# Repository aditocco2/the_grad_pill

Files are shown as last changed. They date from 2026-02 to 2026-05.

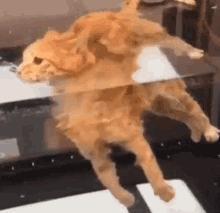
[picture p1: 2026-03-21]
python/media_test/iuh.gif

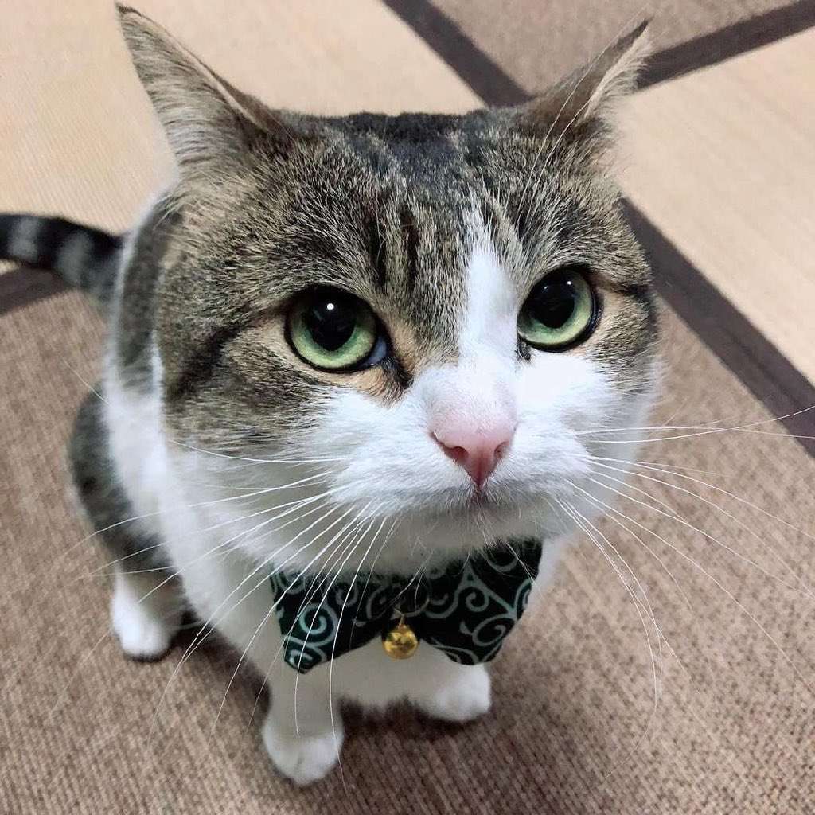
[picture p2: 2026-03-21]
python/media_slideshow/825763.jpg

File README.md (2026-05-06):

# Overblinking: The LED Matrix Graduation Cap

A DIY graduation cap project that shows a slideshow of pictures, GIFs, videos, and scrolling text messages on a 64x64 LED matrix.

Includes a high-performance LED matrix driver, a custom 3D printed mounting system, and a custom PCB.

thumb
staticmodetopdown
modesw

## Features
- Easy loading of data onto the SD card - no manual downscaling or image dumping needed
- SD card is exposed underneath the cap with a custom PCB, allowing easy replacement of cards
- Mode switch allows you to automatically switch to a less distracting "static mode" during speeches
- Whole system is powered through one battery pack
- Optional rain resistance using an acrylic sheet and 3D printed waterproofing shield
- Automatically initializes/recovers SD cards and survives card swaps
- Only required electronics skill for assembly is through-hole soldering

## Build Your Own
For instructions on how to make your own LED matrix graduation cap, read the full guide [here](https://overblinking.substack.com/guide)!

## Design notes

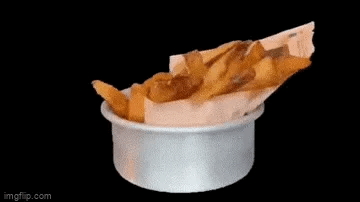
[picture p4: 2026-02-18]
python/media_slideshow/fries2.gif

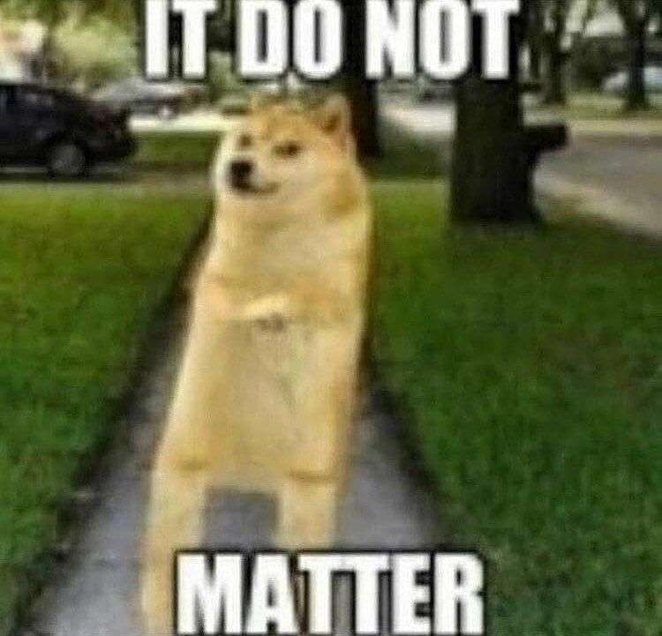
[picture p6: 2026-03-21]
python/media_slideshow/it do not matter.jpg

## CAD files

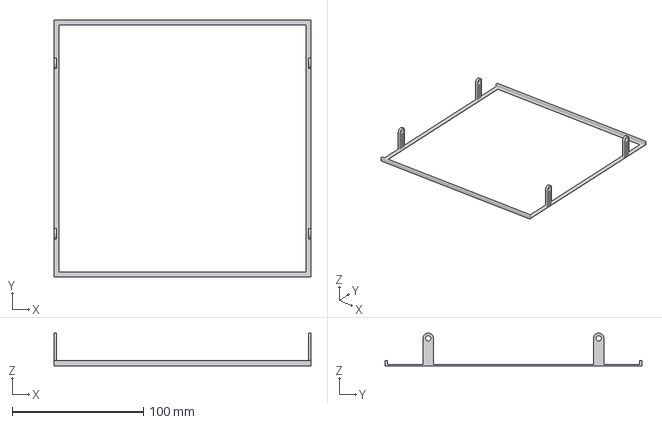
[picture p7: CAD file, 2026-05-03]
models/waterproofing_shield_2.3mf
196.0 x 196.0 x 25.0 mm

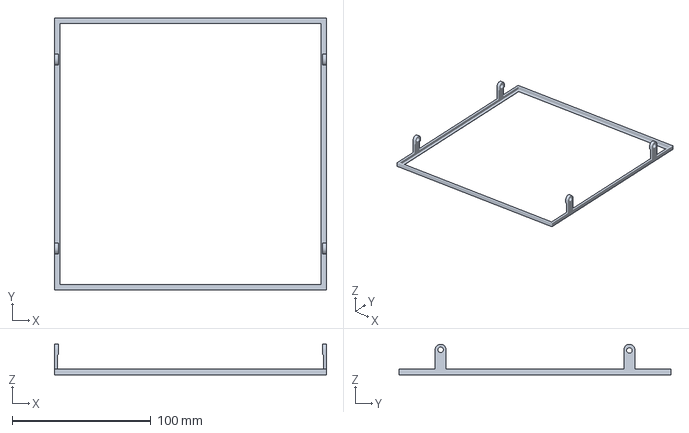
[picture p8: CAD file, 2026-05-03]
models/waterproofing_shield_1.3mf
196.0 x 196.0 x 22.0 mm

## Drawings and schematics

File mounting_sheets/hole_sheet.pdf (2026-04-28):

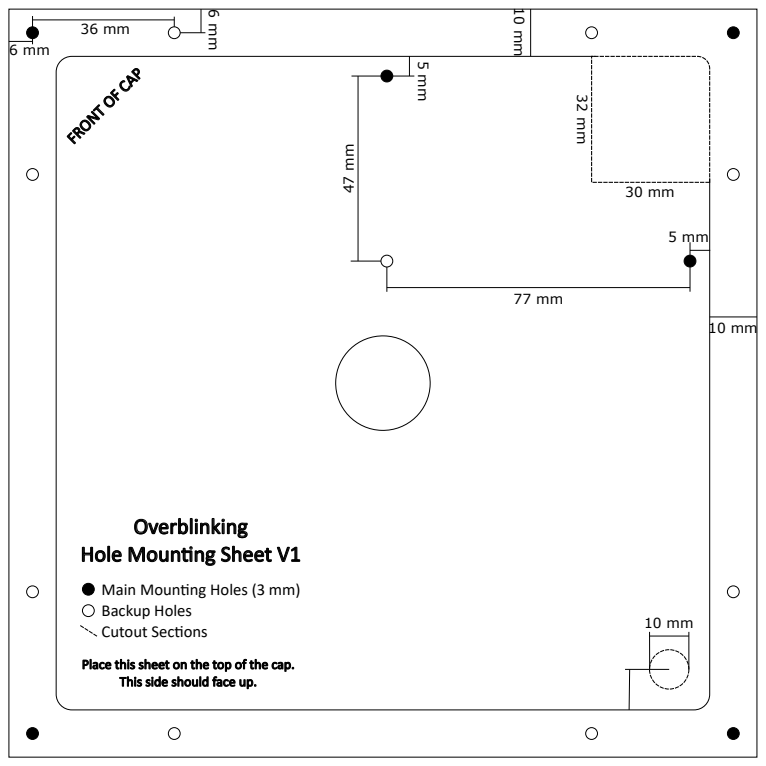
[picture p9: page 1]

FRONT OF CAP

Overblinking
Hole Mounng Sheet V1

Main Mounng Holes (3 mm)
Backup Holes
Cutout Secons

Place this sheet on the top of the cap.
This side should face up.

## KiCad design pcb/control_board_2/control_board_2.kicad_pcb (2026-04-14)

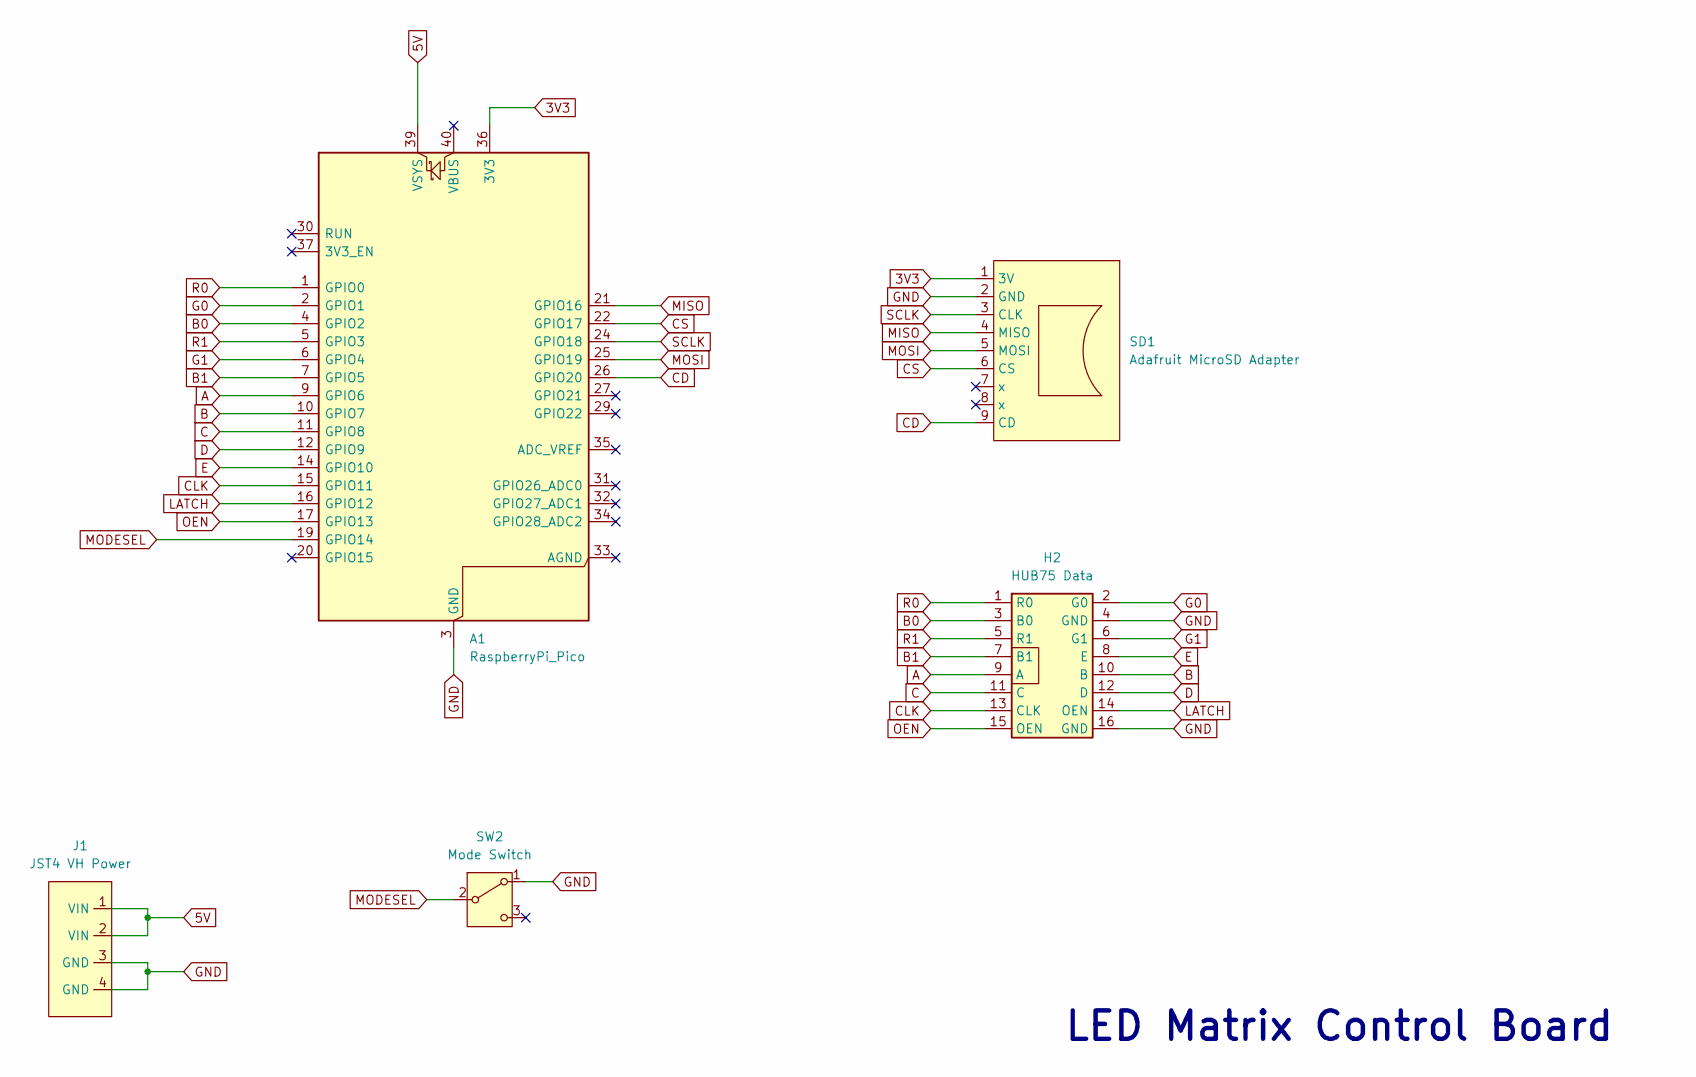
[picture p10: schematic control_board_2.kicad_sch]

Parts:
A1: RaspberryPi_Pico; RaspberryPi_Pico_Common_Unspecified
H2: HUB75 Data; IDC-Header_2x08_P2.54mm_Vertical
J1: JST4 VH Power; JST_VH_B4PS-VH_1x04_P3.96mm_Horizontal
SD1: Adafruit MicroSD Adapter; usd_breakout_adafruit
SW2: Mode Switch; SW_Slide-03_Wuerth-WS-SLTV_10x2.5x6.4_P2.54mm

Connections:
3V3: A1.36 (3V3), SD1.1 (3V)
5V: A1.39 (VSYS), J1.1 (VIN), J1.2 (VIN)
A: A1.9 (GPIO6), H2.9 (A)
B: A1.10 (GPIO7), H2.10 (B)
B0: A1.4 (GPIO2), H2.3 (B0)
B1: A1.7 (GPIO5), H2.7 (B1)
C: A1.11 (GPIO8), H2.11 (C)
CD: A1.26 (GPIO20), SD1.9 (CD)
CLK: A1.15 (GPIO11), H2.13 (CLK)
CS: A1.22 (GPIO17), SD1.6 (CS)
D: A1.12 (GPIO9), H2.12 (D)
E: A1.14 (GPIO10), H2.8 (E)
G0: A1.2 (GPIO1), H2.2 (G0)
G1: A1.6 (GPIO4), H2.6 (G1)
GND: A1.3 (GND), A1.8 (GND), A1.13 (GND), A1.18 (GND), A1.23 (GND), A1.28 (GND), A1.38 (GND), H2.4 (GND), H2.16 (GND), J1.3 (GND), J1.4 (GND), SD1.2 (GND), SW2.1 (A)
LATCH: A1.16 (GPIO12), H2.14 (OEN)
MISO: A1.21 (GPIO16), SD1.4 (MISO)
MODESEL: A1.19 (GPIO14), SW2.2 (B)
MOSI: A1.25 (GPIO19), SD1.5 (MOSI)
OEN: A1.17 (GPIO13), H2.15 (OEN)
R0: A1.1 (GPIO0), H2.1 (R0)
R1: A1.5 (GPIO3), H2.5 (R1)
SCLK: A1.24 (GPIO18), SD1.3 (CLK)

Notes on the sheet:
LED Matrix Control Board

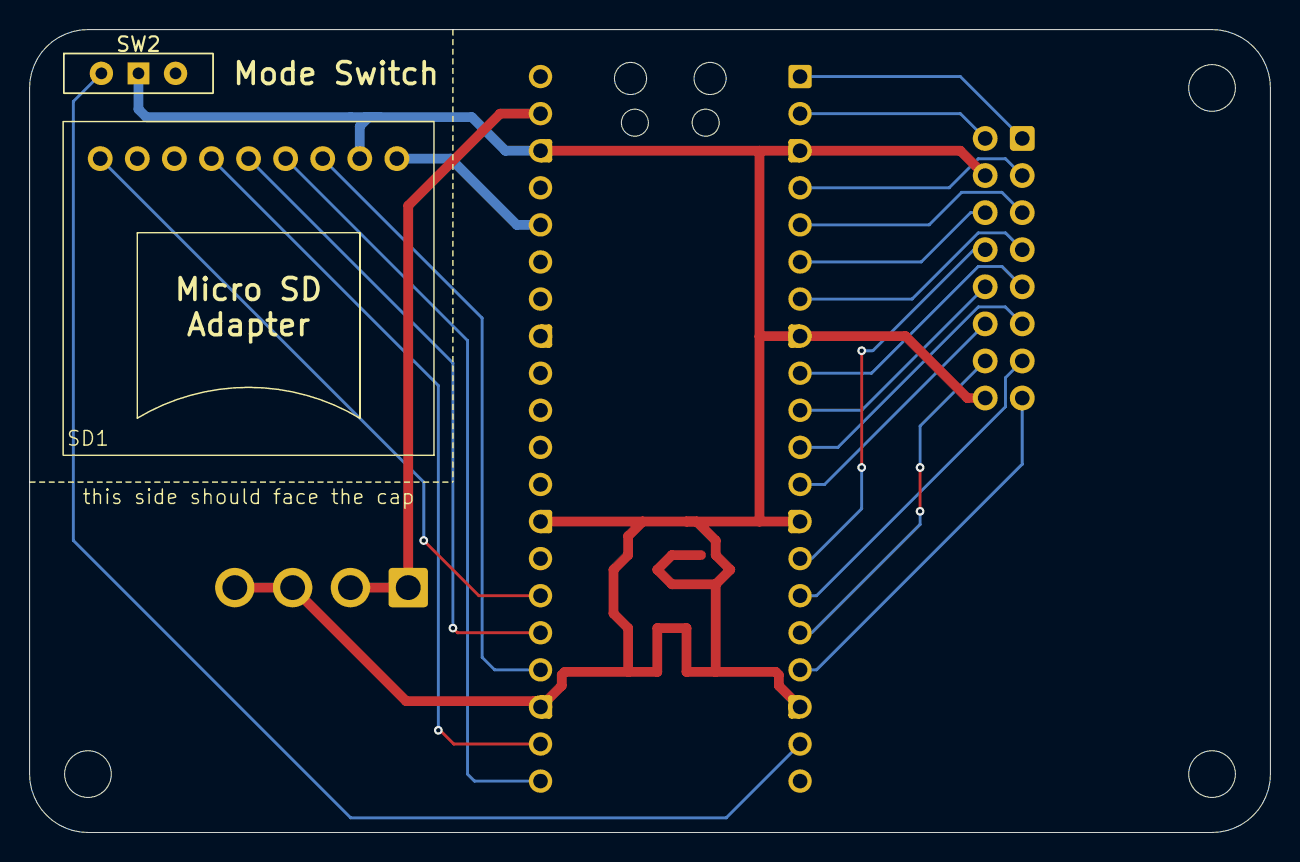
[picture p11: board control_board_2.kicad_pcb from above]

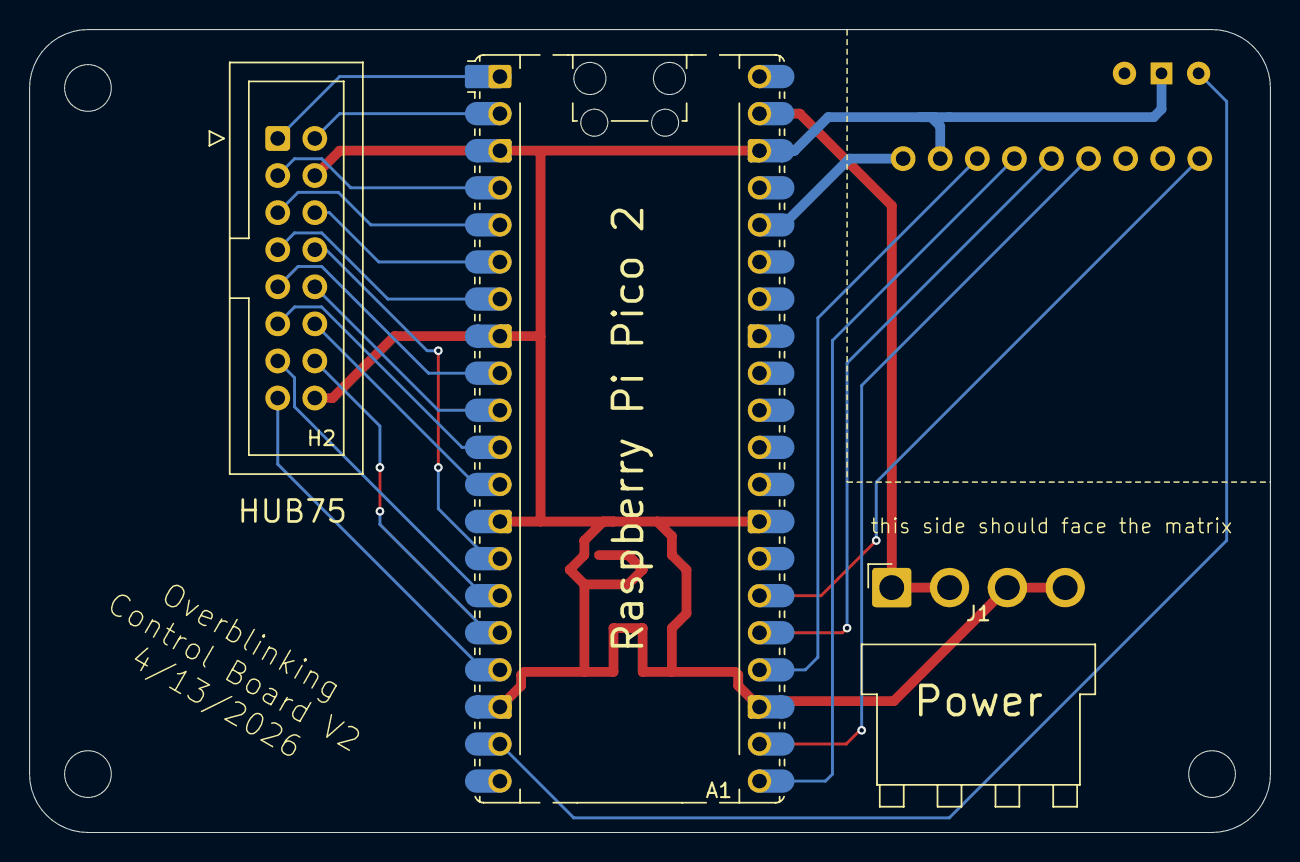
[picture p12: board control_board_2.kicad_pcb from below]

Board: 2 copper layers, 85.0 x 55.0 mm, 5 parts (3 on the bottom side), 23 nets.

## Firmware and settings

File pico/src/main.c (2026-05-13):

// just one more state machine bro, that's all i need

#include <stdio.h>
#include <stdint.h>
#include <string.h>
#include "pico/stdlib.h"
#include "pico/rand.h"
#include "pico/time.h"

#include "sd_card.h"
#include "hub75.h"
#include "hub75_text.h"
#include "rgb565_colors.h"

#define MAX_MEDIA 300
#define TEXT_SCROLLING_PIXELS_PER_SECOND 40

#define TEXT_INST_SEPARATION 16

#define SECTORS_PER_FRAME (WIDTH * HEIGHT * 2 / BLOCK_SIZE)

#define NUM_MEDIA_INDEX 0
#define SWITCH_INTERVAL_INDEX 4
#define USE_STATIC_MODE_INDEX 6
#define RANDOMIZE_INDEX 7

#define TABLE_ROW_WIDTH 16

#define MEDIA_SECTOR_ADDR_INDEX 0
#define N_FRAMES_INDEX 4
#define FRAME_TIME_INDEX 8
#define MEDIA_TYPE_INDEX 15

#define MODESEL 14
#define STATIC_SWITCH_VALUE 0
#define SLIDESHOW_SWITCH_VALUE 1

typedef enum {TEXT, IMAGE, VIDEO} media_type_t;
typedef enum {STATIC, SLIDESHOW} mode_t;

typedef struct{
    uint16_t switch_interval_s;
    _Bool use_static_mode;
    _Bool randomize;

    mode_t current_mode;

    media_type_t current_media_type;
    uint32_t media_address;
    uint16_t frame_duration_ms;
    uint32_t current_media_index;
    uint32_t current_frame_num;
    uint32_t num_frames_in_video;
    uint32_t pool_size;
} player_data_t;

void main_fsm();

void slideshow_media_index_fsm(player_data_t *ts, _Bool reset);
_Bool player_get_metadata(player_data_t *ts, uint8_t *temp_buffer);
_Bool player_load_media(player_data_t *ts, uint8_t *temp_buffer);
_Bool player_get_frame(player_data_t *ts, uint8_t *frame_buffer);
_Bool text_scrolling_fsm(player_data_t *ts, char *str, _Bool reset);
uint16_t color_cycle_rgb565_fsm(_Bool reset);
_Bool mode_switched(player_data_t *ts);
void fill_array_sequentially(uint32_t *arr, uint32_t len);
void shuffle_array(uint32_t *arr, uint32_t len);
void clear_screen();

// Basic timer callbacks that just set flags
struct repeating_timer media_switch_timer, frame_switch_timer;
_Bool media_switch_flag, frame_switch_flag;
_Bool media_switch_cb(__unused repeating_timer_t *rt) {media_switch_flag = true;}
_Bool frame_switch_cb(__unused repeating_timer_t *rt) {frame_switch_flag = true;}

int main(){
    stdio_init_all();

    hub75_configure();
    hub75_set_brightness(20);

    gpio_init(MODESEL);
    gpio_pull_up(MODESEL);
    gpio_set_dir(MODESEL, GPIO_IN);

    while(67){
        main_fsm();
    }
}

void main_fsm(){
    static enum {INIT, GET_METADATA, INVALID_CARD, SWITCH_MODE, 
                 LOAD_MEDIA, INITIALIZE_MEDIA, PLAY_MEDIA} state;

    static player_data_t ts;
    
    static _Bool sd_succ = true;

    uint8_t temp_buffer[BLOCK_SIZE];
    uint8_t *frame_buffer = (uint8_t *)hub75_get_back_buffer();

    if(!sd_succ){
        clear_screen();
        hub75_write_large_text("Insert", 32, 32, ALIGN_CENTER, ALIGN_BOTTOM, RGB565_Red);
        hub75_write_large_text("SD Card", 32, 32, ALIGN_CENTER, ALIGN_TOP, RGB565_Red);
        hub75_update();
        state = INIT;
    }

    switch(state){
        case INIT:
            sd_succ = sd_card_init();
            state = GET_METADATA;
            break;

        case GET_METADATA:
            sd_succ = player_get_metadata(&ts, temp_buffer);
            
            if((*(uint32_t *)&temp_buffer[12]) == 0xe3bedded){
                slideshow_media_index_fsm(&ts, true);
                state = SWITCH_MODE;
            }
            else{
                state = INVALID_CARD;
            }
            break;

        case INVALID_CARD:
            clear_screen();
            hub75_write_large_text("Invalid", 32, 32, ALIGN_CENTER, ALIGN_BOTTOM, RGB565_Red);
            hub75_write_large_text("SD Card", 32, 32, ALIGN_CENTER, ALIGN_TOP, RGB565_Red);
            hub75_update();
            sd_succ = sd_card_check_status();
            break;

        case SWITCH_MODE:
            cancel_repeating_timer(&media_switch_timer);
            if(gpio_get(MODESEL) == STATIC_SWITCH_VALUE && ts.use_static_mode){
                ts.current_mode = STATIC;
            }
            else{
                ts.current_mode = SLIDESHOW;
                if(ts.pool_size > 1){
                    add_repeating_timer_ms(ts.switch_interval_s * 1000, media_switch_cb, NULL, 
                                           &media_switch_timer);
                }
            }
            state = LOAD_MEDIA;
            break;

        case LOAD_MEDIA:
            if(ts.current_mode == STATIC){
                ts.current_media_index = ts.pool_size;
            }
            else{
                slideshow_media_index_fsm(&ts, false);
            }
            sd_succ = player_load_media(&ts, temp_buffer);

            state = INITIALIZE_MEDIA;
            break;
        
        case INITIALIZE_MEDIA:
            if (ts.current_media_type == VIDEO){
                sd_succ = player_get_frame(&ts, frame_buffer);
                hub75_update();
            }
            else if (ts.current_media_type == IMAGE){
                sd_succ = sd_card_read_blocks(ts.media_address, SECTORS_PER_FRAME, frame_buffer);
                hub75_update();
            }
            else if(ts.current_media_type == TEXT){
                sd_succ = text_scrolling_fsm(&ts, temp_buffer, true);
                hub75_update();
            }
            state = PLAY_MEDIA;
            break;

        case PLAY_MEDIA:
            if(media_switch_flag){
                media_switch_flag = false;
                state = LOAD_MEDIA;
            }
            else if(mode_switched(&ts)){
                state = SWITCH_MODE;
            }
            else if(frame_switch_flag && ts.current_media_type == VIDEO){
                frame_switch_flag = false;
                sd_succ = player_get_frame(&ts, frame_buffer);
                hub75_update();
            }
            else if(frame_switch_flag && ts.current_media_type == TEXT){
                frame_switch_flag = false;
                text_scrolling_fsm(&ts, temp_buffer, false);
                hub75_update();
            }
            else{
                sd_succ = sd_card_check_status();
            }
            break;
    }
}

_Bool player_get_metadata(player_data_t *ts, uint8_t *temp_buffer){
    if(!sd_card_read_block(0, temp_buffer, BLOCK_SIZE)){
        return false;
    }

    ts->switch_interval_s = *(uint16_t *)&temp_buffer[SWITCH_INTERVAL_INDEX];
    ts->use_static_mode = *(_Bool *)&temp_buffer[USE_STATIC_MODE_INDEX];
    ts->randomize = *(_Bool *)&temp_buffer[RANDOMIZE_INDEX];

    ts->pool_size = *(uint32_t *)&temp_buffer[NUM_MEDIA_INDEX];
    if(ts->use_static_mode){
        ts->pool_size = ts->pool_size - 1;
    }

    return true;
}

void slideshow_media_index_fsm(player_data_t *ts, _Bool reset){
    static enum {INIT, SHUFFLE, TRAVERSE} state;

    static uint32_t media_index_array[MAX_MEDIA];
    static uint32_t tag = 0;

    if(reset){
        state = INIT;
    }

    switch(state){
        case INIT:
            fill_array_sequentially(media_index_array, ts->pool_size);
            tag = 0;
            if(ts->randomize){
                state = SHUFFLE;
            }
            else{
                state = TRAVERSE;
            }
            break;
        case SHUFFLE:
            shuffle_array(media_index_array, ts->pool_size);
            tag = 0;
            state = TRAVERSE;
            break;
        case TRAVERSE:
            tag++;
            if(ts->randomize && tag >= ts->pool_size - 1){
                state = SHUFFLE;
            }
            else if(tag >= ts->pool_size){
                tag = 0;
            }
            break;
    }

    ts->current_media_index = media_index_array[tag];
}

_Bool player_load_media(player_data_t *ts, uint8_t *temp_buffer){
    
    cancel_repeating_timer(&frame_switch_timer);

    uint32_t table_row = ts->current_media_index + 1;
    uint16_t sector = table_row / (BLOCK_SIZE / TABLE_ROW_WIDTH);
    uint16_t table_row_index = table_row * TABLE_ROW_WIDTH % BLOCK_SIZE;

    if(!sd_card_read_block(sector, temp_buffer, BLOCK_SIZE)){
        return false;
    }

    ts->media_address = *(uint32_t *)&temp_buffer[table_row_index + MEDIA_SECTOR_ADDR_INDEX];

    char media_type_char = *(char *)&temp_buffer[table_row_index + MEDIA_TYPE_INDEX];
    switch(media_type_char){
        case 'i':
            ts->current_media_type = IMAGE;
            break;
        case 'v':
            ts->current_media_type = VIDEO;
            ts->num_frames_in_video = *(uint32_t *)&temp_buffer[table_row_index + N_FRAMES_INDEX];
            ts->frame_duration_ms = *(uint16_t *)&temp_buffer[table_row_index + FRAME_TIME_INDEX];
            ts->current_frame_num = 0;
            add_repeating_timer_ms(ts->frame_duration_ms, frame_switch_cb, NULL, 
                                   &frame_switch_timer);
            break;
        case 't':
            ts->current_media_type = TEXT;
            add_repeating_timer_ms(1000 / TEXT_SCROLLING_PIXELS_PER_SECOND, frame_switch_cb, NULL, 
                                   &frame_switch_timer);
            break;
    }

    return true;
}

_Bool player_get_frame(player_data_t *ts, uint8_t *frame_buffer){
    if(!sd_card_read_blocks(ts->media_address + (ts->current_frame_num * SECTORS_PER_FRAME), 
                            SECTORS_PER_FRAME, frame_buffer)){
        return false;
    }

    ts->current_frame_num = ts->current_frame_num + 1;
    if(ts->current_frame_num == ts->num_frames_in_video){
        ts->current_frame_num = 0;
    }

    return true;
}

_Bool text_scrolling_fsm(player_data_t *ts, char *str, _Bool reset){
    static enum {INIT, SCROLL} state;

    static uint16_t color;
    static int16_t start_x;
    int16_t current_x;
    static uint16_t len;

    if(reset){
        state = INIT;
    }

    switch(state){
        case INIT:
            start_x = WIDTH;

            if(!sd_card_read_block(ts->media_address, str, BLOCK_SIZE)){
                return false;
            }

            len = strlen(str);

            state = SCROLL;
            break;
            
        case SCROLL:
            clear_screen();
            
            color = color_cycle_rgb565_fsm(false);

            start_x--;
            current_x = start_x;

            do{
                hub75_write_medium_text(str, current_x, HEIGHT/2, ALIGN_LEFT, ALIGN_CENTER, color);
                current_x += len * MEDIUM_FONT_WIDTH + TEXT_INST_SEPARATION;
            }while(current_x < WIDTH);

            break;
    }

    return true;
}

uint16_t color_cycle_rgb565_fsm(_Bool reset){

    static enum {INCREASE_G, DECREASE_R, INCREASE_B, DECREASE_G, INCREASE_R, DECREASE_B} state;

    // we are using rgb555 for simplicity here, will convert to rgb565 on the way out
    static uint8_t r = 31;
    static uint8_t g = 0;
    static uint8_t b = 0;

    if(reset){
        state = INCREASE_G;
        r = 31;
        g = 0;
        b = 0;
    }

    switch(state){
        case INCREASE_G:
            g++;
            if(g == 31){
                state = DECREASE_R;
            }
            break;
            
        case DECREASE_R:
            r--;
            if(r == 0){
                state = INCREASE_B;
            }
            break;

        case INCREASE_B:
            b++;
            if(b == 31){
                state = DECREASE_G;
            }
            break;
        
        case DECREASE_G:
            g--;
            if(g == 0){
                state = INCREASE_R;
            }
            break;

        case INCREASE_R:
            r++;
            if(r == 31){
                state = DECREASE_B;
            }
            break;

        case DECREASE_B:
            b--;
            if(b == 0){
                state = INCREASE_G;
            }
            break;   
    }

    // build the rgb565 pixel by shifting the green pixel 1 up
    uint16_t pix = (r << 11) | (g << 6) | (b << 0);
    return pix;
}

_Bool mode_switched(player_data_t *ts){
    if(ts->use_static_mode == false){
        return false;
    }
    else if(ts->current_mode == STATIC && gpio_get(MODESEL) == SLIDESHOW_SWITCH_VALUE){
        return true;
    }
    else if(ts->current_mode == SLIDESHOW && gpio_get(MODESEL) == STATIC_SWITCH_VALUE){
        return true;
    }
    else{
        return false;
    }
}

void fill_array_sequentially(uint32_t *arr, uint32_t len){
    for(uint32_t i = 0; i < len; i++){
        arr[i] = i;
    }
}

void shuffle_array(uint32_t *arr, uint32_t len){
    for(uint32_t i = len - 1; i > 0; i--){
        uint32_t j = get_rand_32() % (i + 1);

        uint32_t temp = arr[j];
        arr[j] = arr[i];
        arr[i] = temp;
    }
}

void clear_screen(){
    for(uint8_t x = 0; x < WIDTH; x++){
        for(uint8_t y = 0; y < HEIGHT; y++){
            hub75_set_pixel(x, y, RGB565_Black);
        }
    }
}

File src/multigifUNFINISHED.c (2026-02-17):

#include "FreeRTOS.h"
#include "task.h"
#include "time.h"
#include "FreeRTOSConfig.h"
#include <pico/stdlib.h>
#include <pico/rand.h>
#include <stdio.h>
#include "hub75.h"
#include "sd_card.h"

#define BUTTON_PIN 20

#define GIF_SWITCH_INTERVAL_MS 5000

void hub75_task(__unused void *params);
void frame_read_task(__unused void *params);
void gif_switch_task(__unused void *params);
void button_task(__unused void *params);
void sd_init_task(__unused void *params);

_Bool hub75_on = true;
uint8_t control_buffer[512];
uint8_t image_buffer[64 * 64 * 2];

uint32_t gif_addr;
uint32_t num_frames;
uint16_t frame_time;
uint32_t frame_num;
uint32_t gif_num, num_gifs;

_Bool sd_init_flag = false;
_Bool data_ready_flag = false;

void main(void){
    stdio_init_all();

    xTaskCreate(hub75_task, "", 256, NULL, 1, NULL);
    xTaskCreate(frame_read_task, "", 256, NULL, 1, NULL);
    xTaskCreate(gif_switch_task, "", 256, NULL, 2, NULL);
    xTaskCreate(button_task, "", 256, NULL, 1, NULL);
    xTaskCreate(sd_init_task, "", 256, NULL, 2, NULL);
    

    vTaskStartScheduler();
}

void hub75_task(__unused void *params){
    hub75_configure();

    hub75_load_image((uint16_t *)image_buffer);

    while(1){
        if(hub75_on){
            hub75_refresh();
        }
        vTaskDelay(1);
    }
}

void button_task(__unused void *params){
    static bool current_state = false, previous_state = false;

    gpio_init(BUTTON_PIN);
    gpio_pull_up(BUTTON_PIN);
    gpio_set_dir(BUTTON_PIN, GPIO_IN);
    
    TickType_t last_time = xTaskGetTickCount();

    while(1){
        previous_state = current_state;
        current_state = !gpio_get(BUTTON_PIN);
    
        if(current_state && !previous_state){
            hub75_on = !hub75_on;
        }

        vTaskDelayUntil(&last_time, pdMS_TO_TICKS(5));
    }
}

void sd_init_task(__unused void *params){

    // init sd card once and re-init if it gets lost
    while(!sd_init_flag){
        vTaskSuspendAll();
        sd_init_flag = sd_card_init();
        xTaskResumeAll();
    }

    while(1){

        if(!sd_init_flag){
            vTaskSuspendAll();
            sd_init_flag = sd_card_init();
            xTaskResumeAll();
        }
        vTaskDelay(1);
    }
}

void frame_read_task(__unused void *params){

    // wait for SD init and data ready
    while(!(sd_init_flag && data_ready_flag)){
        vTaskDelay(1);
    }

    TickType_t last_frame_time = xTaskGetTickCount();

    while(1){

        printf("f");
        
        if(!data_ready_flag){
            vTaskDelay(1);
            continue;
        }

        // Read pixel data from SD card into image buffer each frametime
        if(sd_card_read_blocks((16 * frame_num + gif_addr), 16, image_buffer)){
            sd_init_flag = false;
            vTaskDelay(1);
            continue;
        }

        frame_num++;
        if(frame_num == num_frames){
            frame_num = 0;
        }
        vTaskDelayUntil(&last_frame_time, pdMS_TO_TICKS(frame_time));
    }

}

void gif_switch_task(__unused void *params){

    // wait for SD init
    while(!sd_init_flag){
        vTaskDelay(1);
    }
    
    while(!sd_card_read_block(0, control_buffer, 512)){
        sd_init_flag = false;
        vTaskDelay(1);
    }

    num_gifs = (uint32_t)control_buffer[0];

    TickType_t last_switch_time = xTaskGetTickCount();

    while(1){

        printf("s");

        data_ready_flag = false;

        // Pick a random gif and load its data (address/length/frametime)
        gif_num = get_rand_32() % (num_gifs - 1);
        if(gif_num >= num_gifs){
            gif_num = gif_num + 1;
        }

        uint32_t table_row = gif_num + 1;
        uint16_t sector = table_row / (512 / 16); // 16 bytes per row
        uint16_t table_row_index = table_row * 16 % 512;
        
        if(!sd_card_read_block(sector, control_buffer, 512)){
            printf("Sf");
            sd_init_flag = false;
            vTaskDelay(1);
            continue;
        }

        // table row byte assignment:
        // 0 through 3: sector address
        // 4 through 7: number of frames
        // 8 through 9: frame duration
        // 10 through 15: unused
        gif_addr = (uint32_t)control_buffer[table_row_index];
        num_frames = (uint32_t)control_buffer[table_row_index + 4];
        frame_time = (uint16_t)control_buffer[table_row_index + 8];

        frame_num = 0;

        data_ready_flag = true;

        vTaskDelayUntil(&last_switch_time, pdMS_TO_TICKS(GIF_SWITCH_INTERVAL_MS));
    }
    
}

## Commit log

2026-02-17 modified hub75 driver to use dma and have two buffers
2026-02-17 flicker fixed. sd card recovery still iffy
    [sd_card.c]
2026-02-17 made hub75 driver more secure
2026-02-21 made SD SPI not blocking with DMA, is it worth it?
    this was last night
2026-02-25 Still going
    hub75 driver separation complete, could use some more testing for smaller resolution compatibility
2026-03-21 Somewhat organized project
    [control_board_1.kicad_pcb, control_board_1.kicad_sch, threadless_cube.3mf]
2026-03-21 JLCPCB has violated me
    [control_board_1-B_Cu.gbr, control_board_1-B_Mask.gbr, control_board_1-B_Paste.gbr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]
2026-04-14 control board 2 with switch
    [control_board_2-B_Cu.gbr, control_board_2-B_Mask.gbr, control_board_2-B_Paste.gbr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]
2026-04-28 Added PCB holes to mounting sheet
    Also organized some of the files
2026-05-03 built the final cap. had to make waterproofing shield better
    [waterproofing_shield_1.3mf, waterproofing_shield_2.3mf]
